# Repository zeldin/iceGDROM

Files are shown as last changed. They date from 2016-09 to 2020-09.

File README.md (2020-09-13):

iceGDROM
========

This is an implementation of IDE and the "Sega Packet Interface"
as used by the Dreamcast GD-ROM drive, using an iCE40 FPGA.

In addition to the IDE interface itself, and the accompanying CD-DA
interface, the FPGA bitstream implements an RV32EMC-compatible CPU and
an SD Card interface.  Software running on the CPU responds to
disc access commands from the Dreamcast by fetching data from disc
images on an SD Card.

For more detailed information, please see [the webpage][1].

This is free software (and hardware) licensed under the GNU
General Public License version 3.

Hardware
--------

The hardware is based on the Lattice iCE40-HX8K Breakout Board.
In order to connect this board to the Dreamcast motherboard, a
custom "riser board" with the appropriate connectors and some
additional components is used.  The design files for this can be
found in the `pcb/riser` directory.  The bill of materials can be
found in the file `pcb/riser/bom.txt`.  The pin headers with a `J`
designation should be soldered to the Breakout Board (pins facing downwards).

The components CN4, R8, D1, and JP2 through JP4 are optional.  They
are a passthrough for a slave hard drive, and not used by the GD-ROM
emulator.

For the hardware to be complete, the following additional things are
needed:

* A USB-mini cable to connect CN6 to the Breakout Board.  This is how
  the Breakout Board is powered when not attached to a host computer.
* An SD Card module, to connect to CN5.
* Rubber feet or similar to support the weight of the board in the
  corners not resting on CN1.

Required tools
--------------

To build the FPGA bitstream, the following tools are needed:

* Yosys 0.6
* arachne-pnr
* icestorm

To build the RISC-V software, the following tools are needed:

* riscv32-unknown-elf gcc 10.2.0
* riscv32-unknown-elf binutils 2.34.0

Building
--------

Building is done by running GNU make.  Running make at the top level
will build everything, running it in a subdir will build that part.
Note that building in fpga requires the rv32 stuff to be built first.

The file `rv32/source/config.h` can be modified to adapt to the polarity
of the CD signal on the chosen SD Card module, or to enable debug traces
on the serial port of the FTDI chip.

In order to flash the FPGA bitstream to the breakout board, run
`make flash`.

Making image files
------------------

Building the project will also create a host tool in `tools/obj/makegdimg`
which can create image files from either `.gdi` files (for GD-ROM images)
or from `.nrg` or `.cdi` files (for MIL-CD and audio CD images).  The
image files should be named `DISC0000.GI0`, `DISC0001.GI0` etc on the
SD Card.  To switch between images, extract and reinsert the SD Card.

Acknowledgements
----------------

* RISC-V softcore "VexRiscv" was developed by Charles Papon
* GD-ROM connector pinout was provided by OzOnE
* SD Card and FAT code based on sdfatlib by Bill Greiman
* DiscJuggler reader code based on CDIrip by DeXT/Lawrence Williams

[1]: http://mc.pp.se/dc/gdromemu.html

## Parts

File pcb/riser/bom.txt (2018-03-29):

Quantity  Designation  Description                   Mouser SKU
========  ===========  ============================  =======================
1         -            iCE40-HX8K breakout board     842-ICE40HX8K-B-EVN
2         CN2, CN3     20x2 socket header            517-929975-01-20
2         J3, J4       20x2 pin header               517-929836-01-20
1         CN6          USB A female                  571-292303-3
4         -            11mm spacer                   761-M0540-3-N
4         -            M3 nylon hex nut              534-4688
4         -            M3 nylon screw 16mm           534-29346
1         X1           11.2896MHz oscillator         732-SG210STF11.289S3
1         C1           0.01uF - 0.1uF capacitor      581-CB018B0103J
1         CN1          Molex 52602-0579 connector    538-52602-0579
1         CN5          9 pin header                  517-9611096804AR
4         JP1-JP4      3 pin header                  517-9611036804AR
4         -            Jumper                        571-28815452
5         R2-R6        100 Ohm resistor              603-MFR-25FRF52100R
2         R1, R7       10k Ohm resistor              603-MFR-25FRF5210K
1         CN4          22x2 pin header               517-951244-8622-AR
1         D1           LED 3mm 1.9V 2mA              604-WP710A10LGD
1         R8           1k Ohm resistor               603-MFR-25FRF521K

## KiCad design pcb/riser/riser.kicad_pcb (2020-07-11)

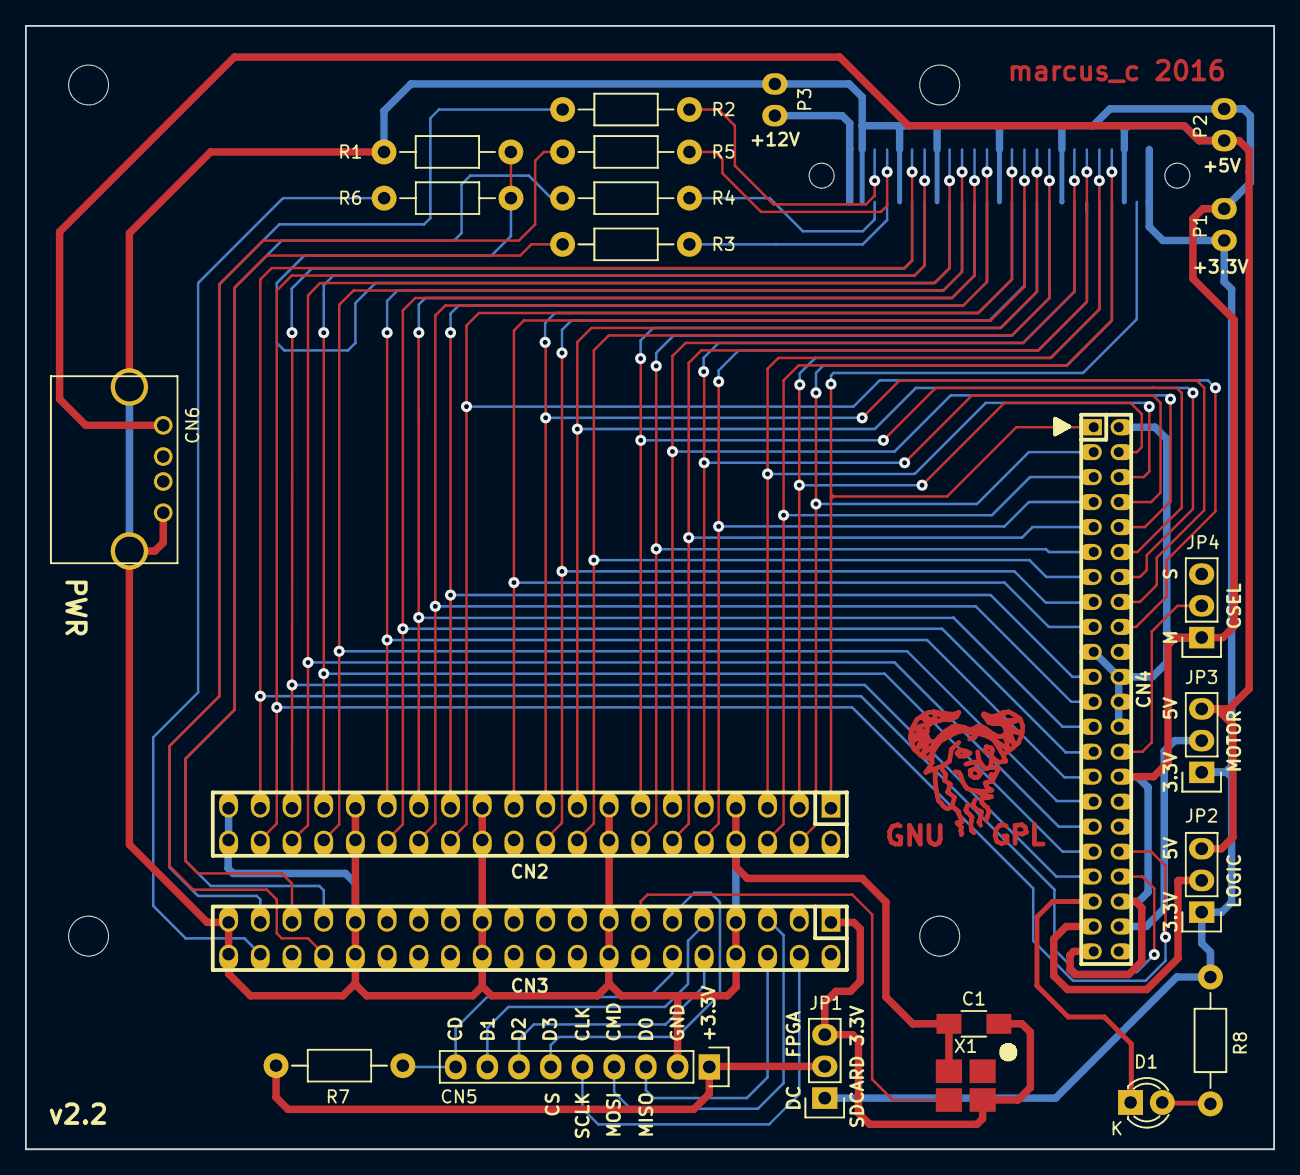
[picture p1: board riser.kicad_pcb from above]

Board: 2 copper layers, 100.0 x 90.0 mm, 24 parts (1 on the bottom side), 57 nets.

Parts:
C1: 0.01u; C_1206_HandSoldering
CN1: Molex_52602_0579
CN2, CN3: CONN_02X20; pin_socket_20x2
CN4: CONN_02X22; pin_strip_2mm_22x2
CN5: CONN_01X09; Pin_Header_Straight_1x09
CN6: USB-A; USB_A
D1: LED; LED-3MM
JP1, JP2, JP3, JP4: JUMPER3; Pin_Header_Straight_1x03
P1, P2, P3: CONN_01X02; WireConnection_1.00mmDrill
R1, R7: 10k; Resistor_Horizontal_RM10mm
R2, R3, R4, R5, R6: 100; Resistor_Horizontal_RM10mm
R8: 1k; Resistor_Horizontal_RM10mm
X1: 11.2896M; SG-210STF

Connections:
+3V3: CN1.A1, CN1.B1, JP1.1, JP2.1, JP3.1, P1.1, R8.1
+3V3_FPGA: C1.1, CN3.1, JP1.3, X1.4
+5V: CN1.A3, CN1.B3, CN6.1, JP2.3, JP3.3, P2.1
+12V: CN1.A25, CN1.B25, P3.1
/A0: CN1.A19, CN2.33, CN4.35
/A1: CN1.B17, CN2.36, CN4.33
/A2: CN1.B19, CN2.38, CN4.36
/ACTIVEn: CN4.39, D1.1
/CCK: CN3.37, R2.1
/CD_CLK: CN1.B23, R2.2
/CS0n: CN1.A20, CN2.35, CN4.37
/CS1n: CN1.B20, CN2.37, CN4.38
/CSEL: CN4.28, JP4.2
/D0: CN1.B11, CN2.21, CN4.17
/D1: CN1.A11, CN2.20, CN4.15
/D2: CN1.B9, CN2.18, CN4.13
/D3: CN1.A9, CN2.14, CN4.11
/D4: CN1.B6, CN2.12, CN4.9
/D5: CN1.A6, CN2.10, CN4.7
/D6: CN1.B4, CN2.6, CN4.5
/D7: CN1.A4, CN2.4, CN4.3
/D8: CN1.A5, CN2.3, CN4.4
/D9: CN1.B5, CN2.5, CN4.6
/D10: CN1.A7, CN2.9, CN4.8
/D11: CN1.B7, CN2.11, CN4.10
/D12: CN1.A10, CN2.13, CN4.12
/D13: CN1.B10, CN2.17, CN4.14
/D14: CN1.A12, CN2.19, CN4.16
/D15: CN1.B12, CN2.26, CN4.18
/DMACKn: CN1.A16, CN2.29, CN4.29
/DMARQ: CN1.A14, CN2.25, CN4.21
/EBCK: CN3.35, R3.1
/ELRCK: CN3.34, R5.1
/EMPH: CN1.A17, R1.1, R6.2
/ESD: CN3.33, R4.1
/G_RST: CN1.A2, CN2.1, CN4.1
/INTRQ: CN1.B16, CN2.34, CN4.31
/IORDY: CN1.B15, CN2.30, CN4.27
/LRCK: CN1.B22, R5.2
/PB0: CN3.38, R6.1
/PB1: CN3.4, CN5.5
/PB2: CN3.5, CN5.4
/PB3: CN3.6, CN5.3
/PB4: CN3.9, CN5.8
/PB5: CN3.10, CN5.7
/PB6: CN3.11, CN5.6
/PB7: CN3.12, CN5.9, R7.1
/RDn: CN1.A15, CN2.27, CN4.25
/REFCLK: CN3.13, X1.3
/SCK: CN1.A22, R3.2
/SDAT: CN1.A23, R4.2
/VLOGIC: CN4.41, JP2.2
/VMOTOR: CN4.42, JP3.2
/WRn: CN1.B14, CN2.28, CN4.23
GND: C1.2, CN1.A8, CN1.A13, CN1.A18, CN1.A21, CN1.A24, CN1.B8, CN1.B13, CN1.B18, CN1.B21, CN1.B24, CN2.7, CN2.8, CN2.15, CN2.16, CN2.23, CN2.24, CN2.31, CN2.32, CN2.39, CN2.40, CN3.7, CN3.8, CN3.15, CN3.16, CN3.23, CN3.24, CN3.31, CN3.32, CN3.39, CN3.40, CN4.2, CN4.19, CN4.22, CN4.24, CN4.26, CN4.30, CN4.40, CN4.43, CN5.2, CN6.4, CN6.5, JP4.1, P1.2, P2.2, P3.2, R1.2, X1.2
unnamed: CN5.1, JP1.2, R7.2
unnamed: D1.2, R8.2

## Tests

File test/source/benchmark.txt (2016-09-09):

Hardware ID   : SEGA SEGAKATANA
Maker ID      : SEGA ENTERPRISES
Device Info   : 0000 GD-ROM1/1
Area Symbols  : JUE
Peripherals   : E000F10
Product No    : T0000
Version       : 1.0
Release Date  : 20160901
Boot Filename : BENCHMARK.BIN
SW Maker Name : Marcus Comstedt
Game Title    : iceGDROM benchmark

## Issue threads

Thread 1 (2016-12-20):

makegdimg doesnt seem to work with nrg images

BadAd84, 2016-12-20:
makegdimg doesnt seem to recognise any nrg images I have tried to use. GDI works fine.

There is also a tool called cdi2nrg, which the resulting files do not work either.

zeldin, 2016-12-20:
Not much to go on here...  It works with all the nrg images I've tried it with obviously.

Could you provide a sample of a file that does not work?  Do you know what sector format it uses?  Do you get any error messages?

BadAd84, 2016-12-20:
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

This is the error message, seems like its just falling through the detection code. I am uploading a test file now

zeldin, 2016-12-20:
Thanks.  This seems to be a pre-Nero5 file, using the old footer format.  I didn't implement support for it since I assumed everyone would be using Nero5 or newer.  I'll see if I can add it.

BadAd84, 2016-12-20:
The above image was created using "cdi2nrg", if you could implement it - it would make things easier if you already have a colllection of CDI's (which as you likely know, was the format used at the time).

Here is another image, but created in nero 2017 which also doesnt work (maybe they updated the format again?).

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

http://www.filedropper.com/image2

zeldin, 2016-12-20:
Well, it would make more sense to implement DiscJuggler support directly then, which is actually on my to-do-list.  :-)
I'll check the other image too.

BadAd84, 2016-12-20:
Excellent, thank you.

To avoid making another issue, are you aware of the performance issues? I have tested some images, but load times are much slower, with audio skipping etc.

zeldin, 2016-12-20:
There is a benchmark program in the git repo that you can try.  I get performance which is similar to physical GD-ROM (and better than CD-R), but it will depend a lot on the speed grade of the SD card.  Seeks can be slow due to the structure of FAT filesystems, but then so are seeks on a physical disk.
I'm planning to do a writeup on performance and the different bottlenecks later.

BadAd84, 2016-12-20:
When I compile, the test folder gas the obj folder created, but nothing is within it.

If you have suggests for fixing that or have the binaries that I can test, I can try a bunch of sd cards.

zeldin, 2016-12-20:
Use `make tests` to build the test stuff.

As for the Nero2017 file, as the error message says it uses track mode 0x0200, which is not one of those listed on https://en.wikipedia.org/wiki/NRG_(file_format).  Since the sector size is 2048 and the number is close to 0x0300, I'm guessing this is CD-XA mode 2 form 1 without the subheader and ECC data.  I don't suppose you can confirm that?

Xerxes3rd, 2016-12-20:
zeldin, do you have a link to the SH4 GCC compiler used in 'make tests'?  I couldn't find it as of a few weeks ago when I was playing with iceGDROM.

zeldin, 2016-12-20:
@Xerxes3rd GCC source code is available from http://gcc.gnu.org/.  Just specify --target=sh-elf when you build it.

zeldin, 2016-12-20:
@BadAd84 Regarding that first (pre Nero-5) image, there's something wonky about it besides using the old Nero format.  There is only one track (#1) listed in the CUES and DAOI chunks, but yet the SINF chunks indicate that there should be two sessions, with one track in each.  That does not add up...

zeldin, 2016-12-21:
@BadAd84 I've now pushed two commits which should handle the 0x200 type of Nero2017, and also the older pre-Nero5 format.  As I mentioned, your `image.nrg` is broken, so it's not going to convert anyway.  The CUES and DAOI chunks specify a single track of 7.5 minutes, which equals 75 megabytes of data.  However, the image file is 777 megabytes large, so there is clearly data there for a second longer track, all the metadata for it is just missing.  So it seems like this `cdi2nrg` tool did not do a proper job.

Closed 2016-12-21.

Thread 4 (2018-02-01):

REplacement delisted parts

jmoleiro, 2018-02-01:
Hi! On Mouser these parts are delisted

9 pin header - 517-9611096804AR
3 pin header - 517-9611036804AR

Any idea which alternative parts can i use?

Thanks

John

zeldin, 2018-02-01:
Hi.  For these headers the exact height isn't important, so basically you can pick any header with 2.54 mm pitch and the correct number of pins.

e.g.
855-M20-9770942
855-M20-9770342
should be suitable replacements.

Closed 2018-02-01.

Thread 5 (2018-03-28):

Wrong cap value

stt, 2018-03-28:
pcb/riser/bom.txt and the website say 0.1uF cap, but the schema and mouser code say 0.01uF, so I'm guessing that's the right one?

catofstealth, 2018-03-29:
The capacitor in question is for the timing crystal oscillator, the datasheet states that a 0.01uF to 0.1uF bypass capacitor is required for stable operation so anything in that range should be fine.

I've literally just built one of these last night with a 0.1uF capacitor and its working fine!

zeldin, 2018-03-29:
As catofstealth says, either value should work fine.  I'll update the webpage and BOM to specify the range instead.

stt, 2018-03-29:
Ah that explains it, didn't look at what it was used for at all. Thanks.

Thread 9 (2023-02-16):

tried build with latest yosys(0.26)/nextpnr(0.5)- results in a design with 25x the LUTs of an ice40?

dirkenstein, 2023-02-16:
Ouput was this?
Any idea what's going on here?

Info: Device utilisation:
Info: 	         ICESTORM_LC: 195891/ 7680  2550%
Info: 	        ICESTORM_RAM:     8/   32    25%
Info: 	               SB_IO:    51/  256    19%
Info: 	               SB_GB:     8/    8   100%
Info: 	        ICESTORM_PLL:     2/    2   100%
Info: 	         SB_WARMBOOT:     0/    1     0%

Info: Placed 57 cells based on constraints.
ERROR: Unable to place cell 'vexrv_inst.ram[988]_SB_DFFE_Q_7_E_SB_DFFE_E_2_DFFLC', no BELs remaining to implement cell type 'ICESTORM_LC'
0 warnings, 1 error

dirkenstein, 2023-02-16:
It's a problem with yosys not recognizing the ram in vexriscv_wrapper.v as BRAM and trying ro implement it a DFFs.
Still breaks in latest yosys but there is a bug reported in relation to it.

zeldin, 2023-02-16:
Yeah, when the number of `ICESTORM_LC` increases explosively for no apparent reason, that is usually what has happened.  :smile:

This is what I get with yosys 0.17 and nextpnr 0.3:

```
Info: Device utilisation:
Info:            ICESTORM_LC:  4546/ 7680    59%
Info:           ICESTORM_RAM:    32/   32   100%
Info:                  SB_IO:    51/  256    19%
Info:                  SB_GB:     8/    8   100%
Info:           ICESTORM_PLL:     2/    2   100%
Info:            SB_WARMBOOT:     0/    1     0%

Info: Placed 57 cells based on constraints.
```
Note that the `ICESTORM_RAM` utilisation is expected to be 100%.
Could you please point me towards the yosys bug report you mentioned?  Thanks.

dirkenstein, 2023-02-16:
I think it's this:

https://github.com/YosysHQ/yosys/issues/3627

But the fix (-no-rw-check on synth_ice40) doesn't resolve your issue. I've tried it on the HEAD release, too.

dirkenstein, 2023-02-16:
Or possibly this:

https://github.com/YosysHQ/yosys/issues/3370

dirkenstein, 2023-02-16:
Is it actually something todo with this? Yosys being formal about BRAM having a clocked output?

https://www.reddit.com/r/yosys/comments/adlsv4/inferring_a_single_cycle_2w1r_register_file_in/
http://zipcpu.com/formal/2018/07/21/zipcpu-icoboard.html

zeldin, 2023-02-16:
Well, the `ram` array _does_ have a clocked output -- the read data is always assigned to `ram_read` on a clock edge.  So it's already specifically written to support the BRAMs of ICE40.

dirkenstein, 2023-02-16:
yes, it is.

This is the wacky thing:

The following code sythesizes correctly:(though i'm not sure it's correct. Verilog huts my head.)

   wire [$clog2(mem_size*256):0] ram_read_addr;

   always @(posedge clk) begin
     if (prog_mode) begin
        ram_read_addr <= prog_addr >> 1;
     end else if (!rst_out) begin
        if (dBus_cmd_valid && !dBus_cmd_payload_wr && dbus_ram_access)
          ram_read_addr <= dBus_cmd_payload_address[15:2];
        else if (ibus_stalled)
          ram_read_addr <= ibus_stall_pc;
        else if (iBus_cmd_valid)
          ram_read_addr <= iBus_cmd_payload_pc[15:2];
     end
     ram_read <= ram[ram_read_addr];
   end

This doesn't synthesize bram either:

  always @(posedge clk)
     if (prog_mode) begin
        ram_read <= ram[prog_addr >> 1];
     end else if (!rst_out) begin
        if (dBus_cmd_valid && !dBus_cmd_payload_wr && dbus_ram_access)
          ram_read <= ram[dBus_cmd_payload_address[15:2]];
        else if (ibus_stalled)
          ram_read <= ram[ibus_stall_pc];
        else if (iBus_cmd_valid)
          ram_read <= ram[iBus_cmd_payload_pc[15:2]];
        else
          ram_read <= ram[0];
     end else
       ram_read <= ram[0];

looks like it doesn't like conditional ouput egister assignments even if every possble condition is covered.

zeldin, 2023-02-17:
That can probably be considered a bug, since it _does_ work in 0.17.  I'll see if I can construct a minimal reproduction recipe.

zeldin, 2023-02-17:
(BTW, your alternate implementation will not work since it introduces an extra cycle of latency for reads.  But it could probably be made to work if the assignments of `ram_read_addr` are moved to an `always @(*)` block instead.)

dirkenstein, 2023-02-17:
Hmm - with always @(*) it fails with:

ERROR: timing analysis failed due to presence of combinatorial loops, incomplete specification of timing ports, etc.

zeldin, 2023-02-17:
You need to put _only_ the assignments of `ram_read_addr` in the `always @(*)`, not anything else (like the assignment of `ram_read`).
Anyway, I have a stand-alone reproduction recipe now, so I'll create a yosys ticket once I minimized it a little more.

zeldin, 2023-02-18:
@dirkenstein I took the liberty of tacking on my reproduction recipe to YosysHQ/yosys#3679.
Also, I pushed a workaround so it should be possible to build iceGDROM with yosys 0.26 now.

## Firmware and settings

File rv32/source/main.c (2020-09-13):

#include <stdint.h>
#include <stdbool.h>

#include "config.h"

#include "hardware.h"
#include "debug.h"
#include "delay.h"
#include "sdcard.h"
#include "ide.h"
#include "cdda.h"
#include "fatfs.h"
#include "imgfile.h"
#include "timer.h"

#if SD_CD_PIN_ACTIVE_HIGH
#define SDCARD_INSERTED (bit_is_set(SD_CD_PIN, SD_CD_BIT))
#else
#define SDCARD_INSERTED (bit_is_clear(SD_CD_PIN, SD_CD_BIT))
#endif

static bool find_imgfile()
{
  if (fatfs_read_rootdir())
    return true;
  fatfs_reset_filename();
  return fatfs_read_rootdir();
}

void handle_sdcard()
{

  DEBUG_PUTS("[Card inserted]\n");

  if (sd_init() &&
      fatfs_mount() &&
      find_imgfile() &&
      imgfile_init()) {
    set_disk_type(imgheader.disk_type);
    PORTA = fatfs_filenumber;
    fatfs_next_filename();
  } else {
    fatfs_reset_filename();
    PORTA = ~0;
  }

  while (SDCARD_INSERTED) {
    service_ide();
    service_cdda();
  }

  DEBUG_PUTS("[Card extracted]\n");
  cdda_stop();
  set_disk_type(0xff);
}

int main()
{
  DDRA = 0xff;
  DDRB = 0x00;
  PORTB = 0x00;
  DDRB |= _BV(EMPH_BIT);
  DEBUG_INIT();
  timer_init();
  sei();

  uint8_t leds = 1;

  for (;;) {
    PORTA = leds;
    delayms(250);
    delayms(250);
    if (!(leds <<= 1))
	leds++;

    service_ide();

    if (SDCARD_INSERTED)
      handle_sdcard();
  }

  return 0;
}

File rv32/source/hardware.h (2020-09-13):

#define SD_CD_PIN PINB
#define SD_CD_BIT PIN7

#define EMPH_BIT PIN0

#ifdef __ASSEMBLER__
#define _MMIO_BYTE(addr) addr
#define _MMIO_WORD(addr) addr
#else
#define _MMIO_BYTE(addr) (*(volatile uint8_t *)(void *)(addr))
#define _MMIO_WORD(addr) (*(volatile uint32_t *)(void *)(addr))
#endif

#define PORTA          _MMIO_BYTE(0xffffff00)
#define PINA           _MMIO_BYTE(0xffffff04)
#define DDRA           _MMIO_BYTE(0xffffff08)
#define PORTB          _MMIO_BYTE(0xffffff10)
#define PINB           _MMIO_BYTE(0xffffff14)
#define DDRB           _MMIO_BYTE(0xffffff18)
#define UDR0           _MMIO_WORD(0xffffff20)
#define UCSR0          _MMIO_WORD(0xffffff24)
#define UBRR0          _MMIO_WORD(0xffffff28)
#define TCNT0          _MMIO_WORD(0xffffff30)
#define OCR0           _MMIO_WORD(0xffffff34)
#define TIFR           _MMIO_WORD(0xffffff38)
#define TIMSK          _MMIO_WORD(0xffffff3c)

#define PIN0           0
#define PIN1           1
#define PIN2           2
#define PIN3           3
#define PIN4           4
#define PIN5           5
#define PIN6           6
#define PIN7	       7

#define PB0         PIN0
#define PB1         PIN1
#define PB2         PIN2
#define PB3         PIN3
#define PB4         PIN4
#define PB5         PIN5
#define PB6         PIN6
#define PB7         PIN7

#define RXC            7
#define TXC            6
#define UDRE           5
#define FE             4
#define DOR            3

#define OCIE0          0
#define OCF0           0

#define IDE_STATUS     _MMIO_BYTE(0xfffef000)
#define IDE_ERROR      _MMIO_BYTE(0xfffef004)
#define IDE_IOCONTROL  _MMIO_BYTE(0xfffef008)
#define IDE_IOPOSITION _MMIO_BYTE(0xfffef00c)
#define IDE_ALT_STATUS _MMIO_BYTE(0xfffef010)
#define IDE_IOTARGET   _MMIO_BYTE(0xfffef014)
#define IDE_DEVCON     _MMIO_BYTE(0xfffef018)
#define IDE_FEATURES   _MMIO_BYTE(0xfffef024)
#define IDE_SECCNT     _MMIO_BYTE(0xfffef028)
#define IDE_SECNR      _MMIO_BYTE(0xfffef02c)
#define IDE_CYLLO      _MMIO_BYTE(0xfffef030)
#define IDE_CYLHI      _MMIO_BYTE(0xfffef034)
#define IDE_DRVHEAD    _MMIO_BYTE(0xfffef038)
#define IDE_COMMAND    _MMIO_BYTE(0xfffef03c)

#define IDE_DATA_BUFFER  ((uint8_t *)0xfffef400)

#define SDCARD_CONTROL _MMIO_BYTE(0xfffee400)
#define SDCARD_DATA    _MMIO_BYTE(0xfffee404)
#define SDCARD_DIVIDER _MMIO_BYTE(0xfffee408)
#define SDCARD_CRC16   _MMIO_WORD(0xfffee410)
#define SDCARD_CRC7    _MMIO_BYTE(0xfffee414)

#define CDDA_CONTROL   _MMIO_BYTE(0xfffee800)
#define CDDA_READPOS   _MMIO_BYTE(0xfffee804)
#define CDDA_LIMIT     _MMIO_BYTE(0xfffee808)
#define CDDA_SCRATCHPAD _MMIO_BYTE(0xfffee80c)

#define CDDA_DATA_BUFFER ((uint8_t *)0xfffeec00)

#ifdef __ASSEMBLER__
#define _BV(bit) (1<<(bit))
#else
#define _BV(bit) (1U<<(bit))
#endif

#define bit_is_clear(reg, bit) (!((reg) & _BV(bit)))
#define bit_is_set(reg, bit) (!bit_is_clear(reg, bit))
#define loop_until_bit_is_clear(reg, bit) do { } while(!bit_is_clear(reg, bit))
#define loop_until_bit_is_set(reg, bit) do { } while(!bit_is_set(reg, bit))

#define cli() asm volatile("csrrci zero,mstatus,8" ::: "memory")
#define sei() asm volatile("csrrsi zero,mstatus,8" ::: "memory")

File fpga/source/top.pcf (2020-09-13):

set_io LED0 B5
set_io LED1 B4
set_io LED2 A2
set_io LED3 A1
set_io LED4 C5
set_io LED5 C4
set_io LED6 B3
set_io LED7 C3
set_io RXD B10
set_io TXD B12
# For use with breakout board, connect 11.2896MHz oscillator to L3
# set_io clk J3
set_io clk L3
set_io PORTB0 B2
set_io PORTB1 R1
set_io PORTB2 P1
set_io PORTB3 P2
set_io PORTB4 N3
set_io PORTB5 N2
set_io PORTB6 M2
set_io PORTB7 M1
set_io CDCLK  B1
set_io SCK    C1
set_io SDAT   D1
set_io LRCK   D2

set_io G_RST  R16
set_io D8     T15
set_io D7     T16
set_io D9     T13
set_io D6     T14
set_io D10    N12
set_io D5     P13
set_io D11    N10
set_io D4     M11
set_io D12    T11
set_io D3     P10
set_io D13    T10
set_io D2     R10
set_io D14    P8
set_io D1     P9
set_io D15    T8
set_io D0     T9
set_io DMARQ  T7
set_io WRn    R6
set_io RDn    T6
set_io IORDY  R5
set_io DMACKn T5
set_io INTRQ  R4
set_io CS0n   R2
set_io CS1n   T1
set_io A0     R3
set_io A1     T3
set_io A2     T2

set_frequency clkout 79.0272
set_frequency clkout_cpu 39.5136

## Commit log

2016-01-09 Assign SPI and PORTB to external pins
2016-01-10 Track dependencies
2016-01-10 Init SD card when inserted
2016-01-11 Fix fosc/2 mode for SPI
2016-01-17 Use 11.2896MHz oscillator instead of 12MHz
    [main.c, top.pcf]
2016-02-02 Assign SPI as alternate functions on PORTB, like on ATmega32u4
2016-02-02 Separate SDcard I/O into a separate file, plus various fixes
    [main.c, sdcard.c]
2016-02-05 Fix prototype for debug_init()
2016-02-05 Lower SPI speed for more reliable operation
2016-02-06 Mount FAT volume
2016-02-21 Set the HRST bit on hard reset
    [ide_interface.v]
2016-02-21 Set BSY on hard reset and on data transfer complete
    [ide_interface.v]
2016-02-28 Fix mapping of sdcard detect which was wrong after PORTB redesign
    [hardware.h]
2016-03-01 Move data access functionality to main thread of execution
2016-03-20 Implemented DMA
2016-04-02 Make COMMAND register controlled by IDE bus regardless of BSY state
    The AVR never writes to this register anyway, and the interface needs
    to be able to react to DMA command aborts.
2016-05-29 New clock configuration
    AVR core runs at oscillator*1.5 (17 MHz).
    IDE interface runs at 4x CPU speed (68 MHz).
    [sdcard.c]
2016-05-29 Implement DMA read (hardcoded cluster mapping for now)
2016-06-12 Move SPI_CS to PB6, and reverse polarity of SD_CD
    [main.c, sdcard.c]
2016-07-03 Add design files for breakout board riser
    [riser.kicad_pcb, riser.sch]
2016-07-03 Update pin mapping for new design
2016-07-03 Tweak mounting hole positions
    [riser.kicad_pcb]
2016-07-14 Unmap PORTB0 as SPI slave select in (it's now used for EMPH)
2016-07-14 Final pin mapping update
2016-07-15 Swap byteorder of CD-DA to match Dreamcast internal format
    [cdda_interface.v]
2016-07-22 New SPI implementation for higher transfer rates
2016-07-22 Create a DMA channel from SDCARD to IDE buffer
2016-07-22 Fix timer interrupt for new CPU clock
2016-07-23 Use SDCARD DMA also for CDDA data
2016-07-24 Retry if sdcard read fails
    [sdcard.c]
2016-07-24 Remove pointless debug trace
2016-07-26 Cache TOCs in RAM and use them to get CDDA track # and EMPH flag
2016-07-26 Increase number of cache slots to use new larger DM
2016-07-27 Use LEDs to indicate SDCARD activity, and which image is selected
2016-07-29 Add missing schematic library
    [riser.sch]
2016-07-29 Fix broken standard components
    [riser.sch]
2016-08-07 Add a BOM for the riser board
2016-09-24 Avoid wasting 2 BRAMs in IDE buffer...
    [ide_data_buffer.v, ide_interface.v]
2016-12-20 makegdimg: Add Nero track type 0x0200
2017-07-02 Decrease via drill size to get a larger annular ring
    [riser.kicad_pcb]
2017-07-07 Add a DMA transfer test program
2018-03-29 Change capacitor value in BOM to a range
    Any value in this range is fine according to the SPXO datasheet.
2019-07-03 Updating the schematic file to include the new style of referencing kicad components with some minor aesthetic changes. Also updating orientation of the LED in the PCB.
    [riser.kicad_pcb, riser.sch]
2020-07-08 Fix multiple read glitch in PIO mode
    [ide_interface.v]
2020-07-09 AVR109: Fix flash addressing
    [avr109.v]
2020-07-09 AVR109: Flush TX on attaching
2020-07-11 Ignore footprint info cache
2020-08-08 Replace AVR core with RISC-V
    [cdda_interface.v]
2020-09-12 Replace picorv32 with VexRiscv
    [VexRiscv.v, hardware.h]
2020-09-13 Fix bad sdcard indicator
    [main.c]
2023-02-18 Workaround for yosys > 0.17 failing to infer BRAM
    [vexriscv_wrapper.v]
